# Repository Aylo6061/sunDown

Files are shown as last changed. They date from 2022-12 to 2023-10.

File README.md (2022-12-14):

# sunDown
Color temperature tunable lamp.

# Programming over USB
This program pulls the wifi credentials from a file stored in SPIFFS.  This file should be called "creds.txt" and needs to be added to /data.  The contents should be something like:

	{"ssid":"my_network_name", "pwd":"my_secret_password"}

This file is not included, for obvious reasons.  Once this file is in place, proceed to the next step.

Open sunDown.ino in the arduino IDE, and build/upload the code with ctrl+u or the upload button. Once this is done, use the [ESP32 sketch data upload](https://github.com/esp8266/arduino-esp8266fs-plugin) to upload the data folder.

This firmware uses [elegant ota](https://github.com/ayushsharma82/ElegantOTA). Refer to documentation there on running an OTA update.

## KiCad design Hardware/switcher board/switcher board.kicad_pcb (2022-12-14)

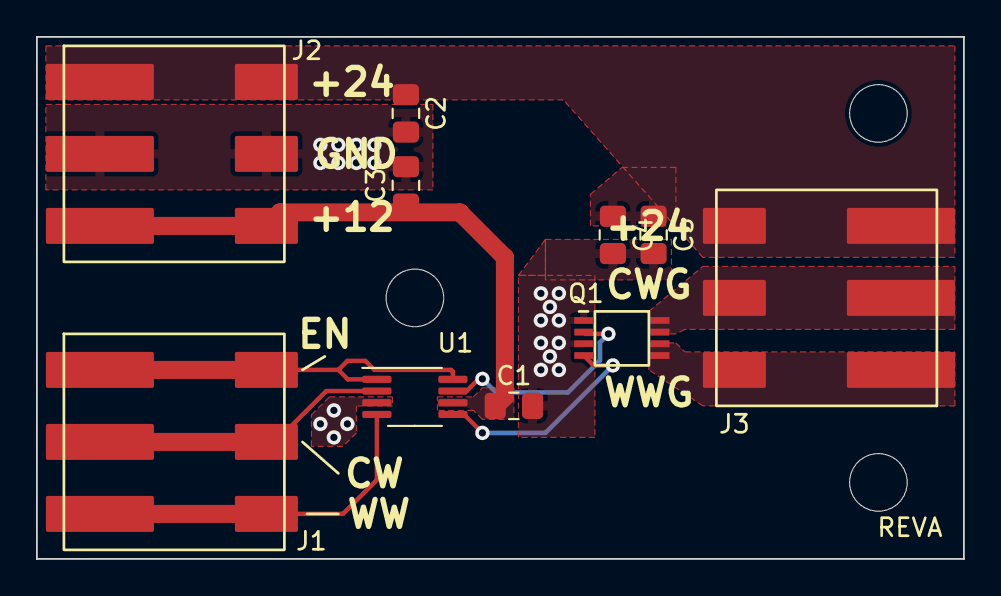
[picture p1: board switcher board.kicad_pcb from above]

Board: 2 copper layers, 51.5 x 29.0 mm, 13 parts (0 on the bottom side), 10 nets.

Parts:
C1, C2, C3, C4, C5: C; C_0805_2012Metric_Pad1.18x1.45mm_HandSolder
H1, H2, H3: MountingHole; MountingHole_3.2mm_M3
J1, J2, J3: Screw_Terminal_01x03; 2060-453
Q1: IRF7503TRPBF; IR Micro8
U1: MCP14A0154-E/MS; MSOP-8_3x3mm_P0.65mm

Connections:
+12V: C1.1, C3.1, J1.3, U1.6 (Vdd)
+24V: C2.1, C4.1, C5.1, J1.1, J3.3
/CW: J2.2, U1.2 (IN_A)
/CW_Gnd: J3.2, Q1.7 (D2), Q1.8 (D2)
/EN: J2.1, U1.1 (EN_A), U1.8 (EN_B)
/WW: J2.3, U1.4 (IN_B)
/WW_Gnd: J3.1, Q1.5 (D2), Q1.6 (D2)
GND: C1.2, C2.2, C3.2, C4.2, C5.2, J1.2, Q1.1 (S2), Q1.3 (S2), U1.3 (GND)
unnamed: Q1.2 (G2), U1.7 (OUT_A)
unnamed: Q1.4 (G2), U1.5 (OUT_B)

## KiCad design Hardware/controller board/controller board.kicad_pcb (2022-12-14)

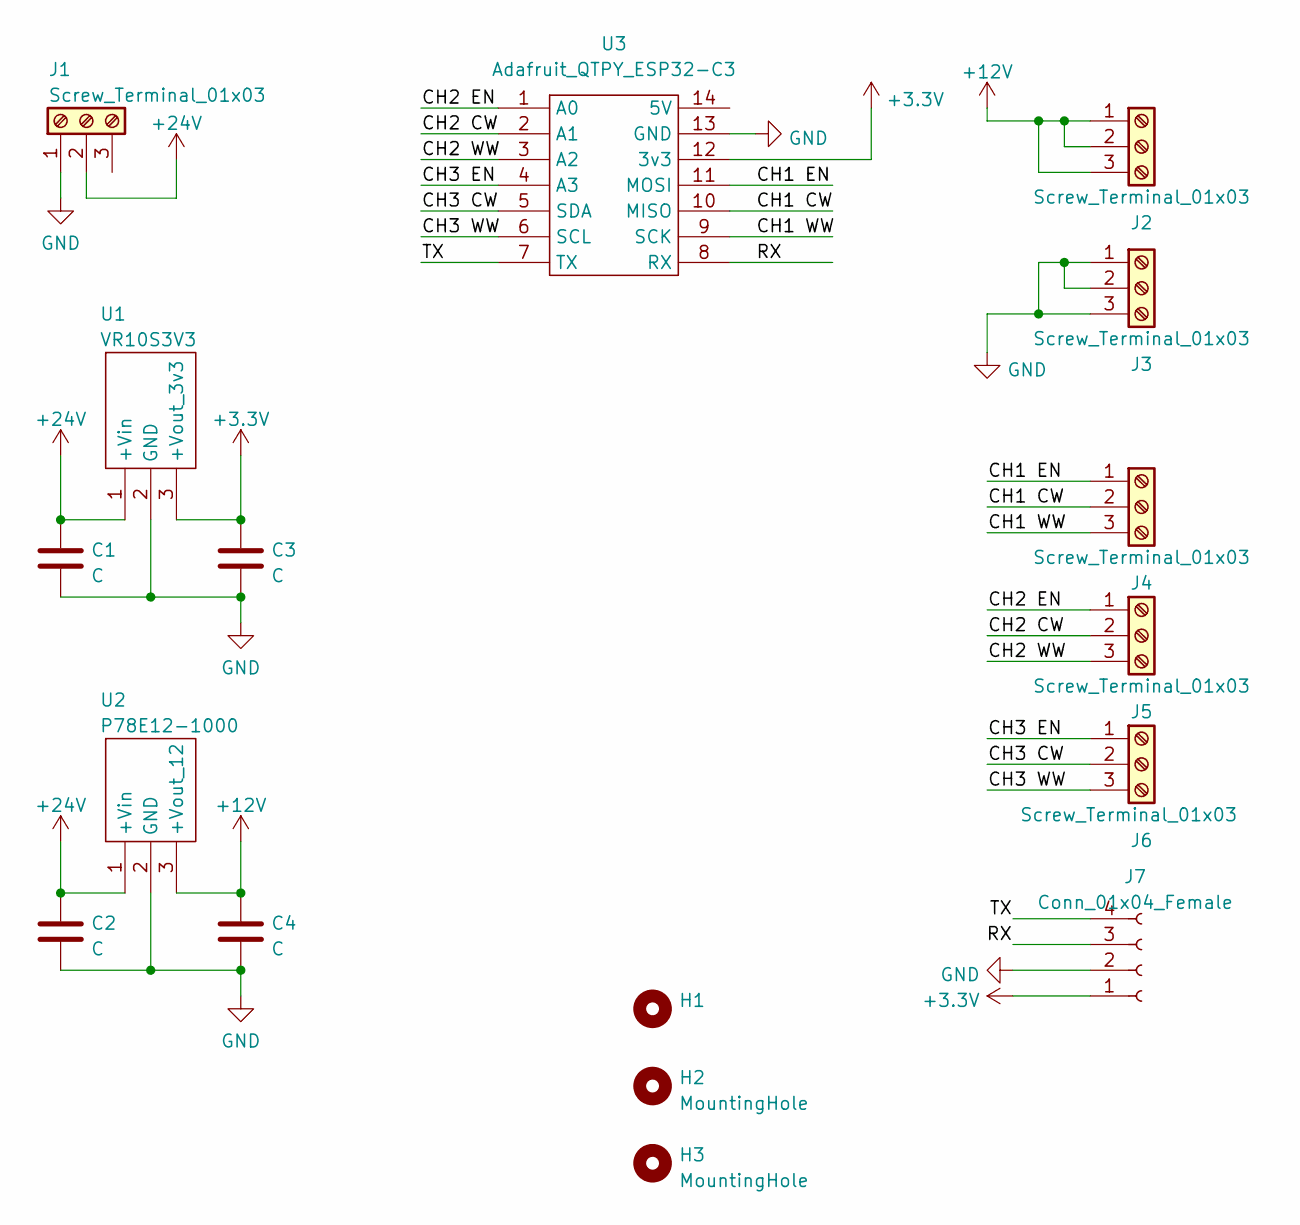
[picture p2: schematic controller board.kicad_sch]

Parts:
C1, C2, C3, C4: C; C_0805_2012Metric_Pad1.18x1.45mm_HandSolder
H1: (no value)
H2, H3: MountingHole
J1, J2, J3, J4, J5, J6: Screw_Terminal_01x03; 2060-453
J7: Conn_01x04_Female; PinHeader_1x04_P2.54mm_Vertical_SMD_Pin1Left
U1: VR10S3V3; 3pinDCDC
U2: P78E12-1000; 3pinDCDC
U3: Adafruit_QTPY_ESP32-C3; QTPY ESP32 C3_MSMD

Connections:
+3V3: C3.1, J7.1, U1.3 (+Vout_3v3), U3.12 (3v3)
+12V: C4.1, J2.1, J2.2, J2.3, U2.3 (+Vout_12)
+24V: C1.1, C2.1, J1.2, U1.1 (+Vin), U2.1 (+Vin)
/CH1 CW: J4.2, U3.10 (MISO)
/CH1 EN: J4.1, U3.11 (MOSI)
/CH1 WW: J4.3, U3.9 (SCK)
/CH2 CW: J5.2, U3.2 (A1)
/CH2 EN: J5.1, U3.1 (A0)
/CH2 WW: J5.3, U3.3 (A2)
/CH3 CW: J6.2, U3.5 (SDA)
/CH3 EN: J6.1, U3.4 (A3)
/CH3 WW: J6.3, U3.6 (SCL)
/RX: J7.3, U3.8 (RX)
/TX: J7.4, U3.7 (TX)
GND: C1.2, C2.2, C3.2, C4.2, J1.1, J3.1, J3.2, J3.3, J7.2, U1.2 (GND), U2.2 (GND), U3.13 (GND)

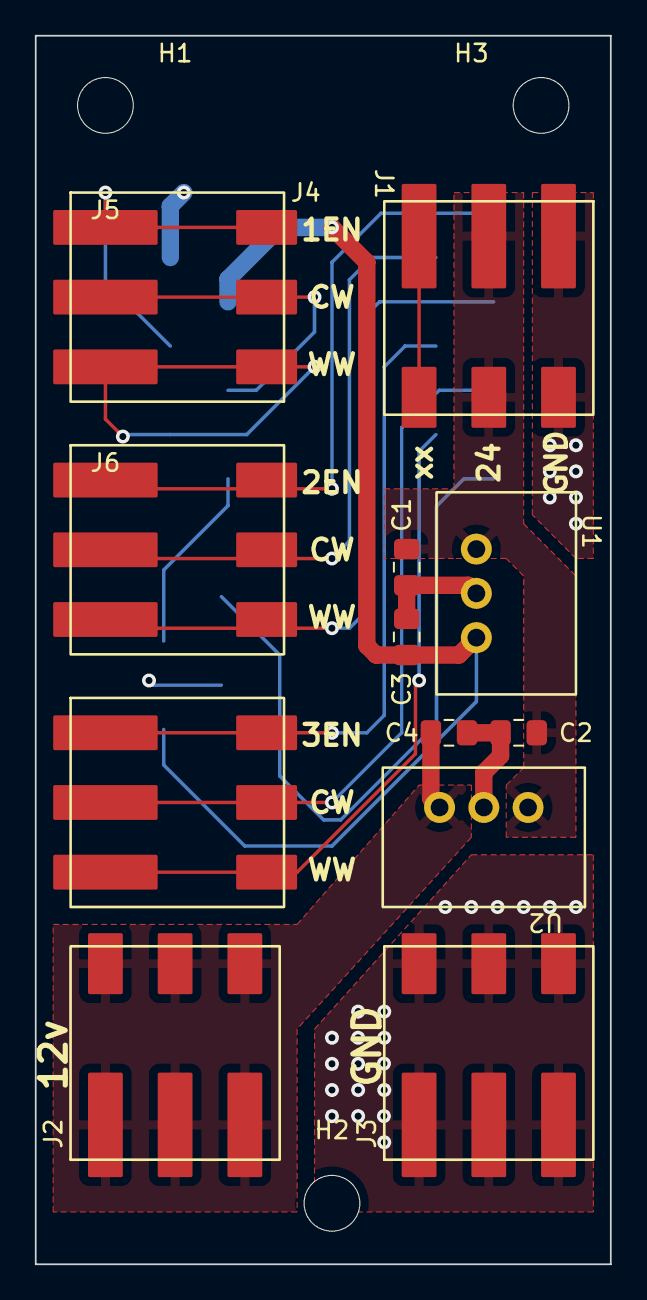
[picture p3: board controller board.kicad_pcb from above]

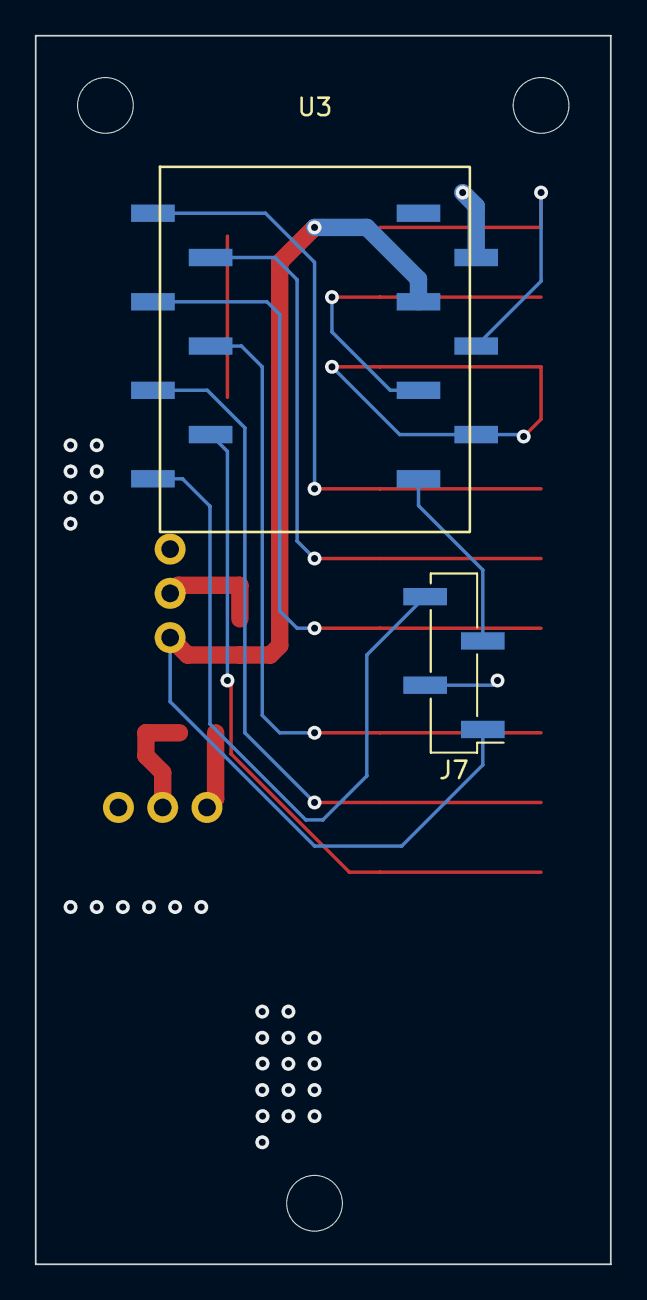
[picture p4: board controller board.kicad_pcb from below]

Board: 4 copper layers, 33.0 x 70.5 mm, 17 parts (2 on the bottom side), 15 nets.

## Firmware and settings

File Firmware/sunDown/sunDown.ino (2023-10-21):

#if defined(ESP8266)
  #include <ESP8266WiFi.h>
  #include <ESPAsyncTCP.h>
#elif defined(ESP32)
  #include <WiFi.h>
  #include <AsyncTCP.h>
#endif

#include <ESPAsyncWebServer.h>
#include <AsyncElegantOTA.h>
#include <SPIFFS.h>
#include <ArduinoJson.h>

#define CW1 8
#define WW1 10

#define CW2 3
#define WW2 1

#define CW3 5
#define WW3 6

AsyncWebServer server(80);

// Set your Static IP address
IPAddress local_IP(10, 0, 0, 184);
// Set your Gateway IP address
IPAddress gateway(10, 0, 0, 1);

IPAddress subnet(255, 255, 0, 0);

struct State {
  int mode;
  int intensity;
  int temperature;
};

struct State state;

void initSPIFFS() {
  if (!SPIFFS.begin(true)) {
    Serial.println("An error has occurred while mounting SPIFFS");
  }
  Serial.println("SPIFFS mounted successfully");
}

void all_set(int duty)
{
   for(int i=0; i<6; i++)
  {
    ledcWrite(i,duty);
  }
}

void warm_set(int duty)
{
   for(int i=3; i<6; i++)
  {
    ledcWrite(i,duty);
  }
}

void cool_set(int duty)
{
   for(int i=0; i<3; i++)
  {
    ledcWrite(i,duty);
  }
}

void setup(void) {

  
  Serial.begin(115200);
  Serial.println("first things first");

  //reset state
  state.mode = 1;
  state.intensity = 512;
  state.temperature = 0;
  
  for(int i=0; i<6; i++)
  {
    if(!ledcSetup(i, 25000,10))
    {
      Serial.println("failed to setup led!");
      while(1)
      {
        //do nothing
      }
    }
  }

  for(int i=0; i<6; i++)
  {
    ledcWrite(i,1023);
  }

  ledcAttachPin(CW1, 0);
  ledcAttachPin(CW2, 1);
  ledcAttachPin(CW3, 2);
  ledcAttachPin(WW1, 3);
  ledcAttachPin(WW2, 4);
  ledcAttachPin(WW3, 5);
  
  initSPIFFS();
  if(!WiFi.config(local_IP, gateway, subnet))
  {
    Serial.println("STA Failed to configure");
  }

  File wifiCreds = SPIFFS.open("/creds.txt","r");
  DynamicJsonDocument doc(512U);
    if (DeserializationError::Ok == deserializeJson(doc, wifiCreds))
    {
      JsonObject credJson = doc.as<JsonObject>();
      WiFi.mode(WIFI_STA);
      WiFi.setTxPower(WIFI_POWER_19_5dBm);
      WiFi.begin(credJson["ssid"].as<String>().c_str(), credJson["pwd"].as<String>().c_str());
    }
    else{
      Serial.println("failed to retrieve credentials from SPIFFS.");
      while(1){
        //do nothing
      }
    }
  Serial.println("");
  

  // Wait for connection
  while (WiFi.status() != WL_CONNECTED) {
    delay(500);
    Serial.print(".");
  }
  Serial.println("");
  Serial.print("Connected!!");
  Serial.print("IP address: ");
  Serial.println(WiFi.localIP());

  server.on("/", HTTP_GET, [](AsyncWebServerRequest *request) {
    request->send(200, "text/plain", "Hi, im a lamp!");
  });

  server.on("/lamp", HTTP_GET, [](AsyncWebServerRequest *request) {
    request->send(SPIFFS, "/lamp.htm");
  });

    server.on("/scripts.js", HTTP_GET, [](AsyncWebServerRequest *request) {
    request->send(SPIFFS, "/scripts.js");
  });

  server.on("/status.js", HTTP_GET, [](AsyncWebServerRequest *request) {
    String jsonStateStr;;
    StaticJsonDocument<512> jsonState;
    jsonState["mode"] = state.mode;
    jsonState["temperature"] = state.temperature;
    jsonState["intensity"] = state.intensity;
    serializeJson(jsonState, jsonStateStr);
    request->send(200, "application/json", jsonStateStr);
  });

  server.on(
    "/lamp",
    HTTP_POST,
     [](AsyncWebServerRequest *request){
    //nothing and dont remove it
  }, NULL, [](AsyncWebServerRequest *request, uint8_t *data, size_t len, size_t index, size_t total){
    DynamicJsonDocument jsonDoc(512U);
    if (DeserializationError::Ok == deserializeJson(jsonDoc, (const char*)data))
                {
                    JsonObject obj = jsonDoc.as<JsonObject>();

//                    Serial.printf("%s\n", obj["int"].as<String>().c_str());
                if(obj["cmd"] == "set"){
                warm_set(obj["warm"].as<int>());
                cool_set(obj["cool"].as<int>());
                state.mode = obj["mode"].as<int>();
                state.temperature = obj["temperature"].as<int>();
                state.intensity = obj["intensity"].as<int>();
                }

                request->send(200, "text/plain", "OK");
    } 
    else {
      request->send(404, "text/plain", "");
    }
  });
 
  AsyncElegantOTA.begin(&server);    // Start AsyncElegantOTA
  server.begin();
  Serial.println("HTTP server started");
}

void loop(void) {
}

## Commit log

2022-12-14 added hardware (PCB) files
    [controller board-B_Cu.gbr, controller board-B_Mask.gbr, controller board-B_Paste.gbr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]
2022-12-14 turn TX power all the way up
